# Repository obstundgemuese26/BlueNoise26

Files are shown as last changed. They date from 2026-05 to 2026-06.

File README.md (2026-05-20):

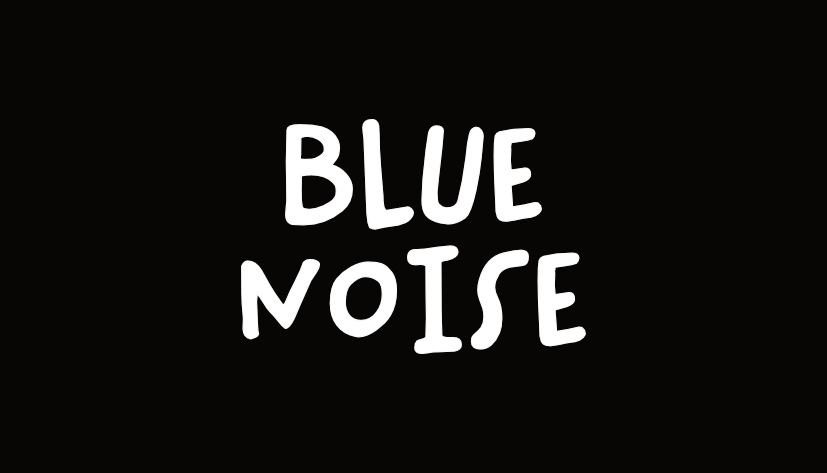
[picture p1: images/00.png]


### Open-source Wireless Jamming Pentesting Device using ESP32-WROOM-32U & 2 NRFL01+PA+LNA Modules

 ---
# WHAT DOES IT DO?

**IT CREATES NOISE SIGNAL TO JAM BLUETOOTH AND WIFI USING NRF24L01 AND ESP32 IN RANGE 2.4GHZ DEVICES, EFFECTS MAY VARY DEPENDS ON DEVICE BLUETOOTH VERSIONS....WARNING!!! JAMMING IS ILLEGAL**

---

## REQUIRED DEVICE AND MODULE:
1. `NRF24L01+ PLUS – PA LNA SMA Antenne`
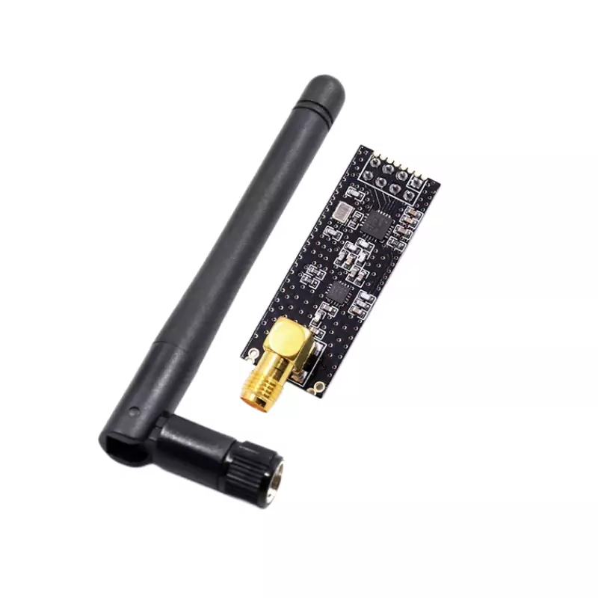
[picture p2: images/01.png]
-  

2. `1pc ESP32U` 
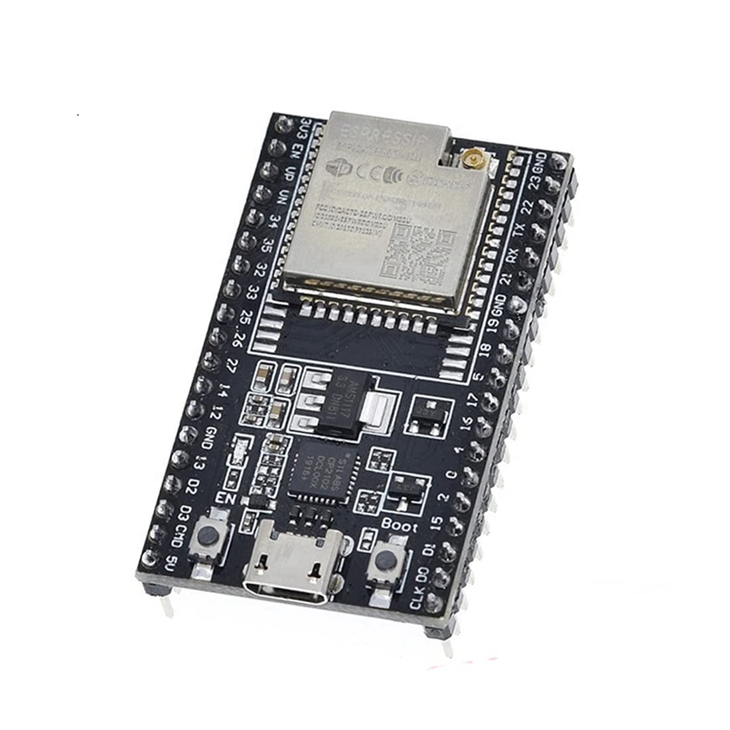
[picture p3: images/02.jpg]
- 

3. `25V 47UF CAPACITORF` 
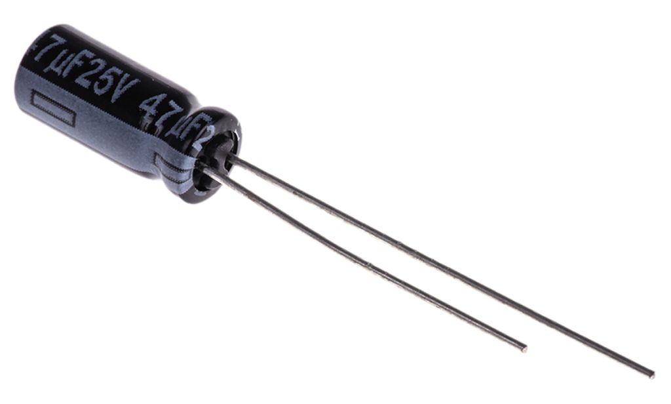
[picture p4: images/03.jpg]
- 

4. `1 DIP SWITCH` 
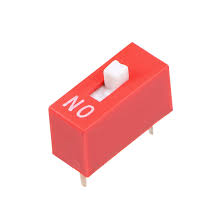
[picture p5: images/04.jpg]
- 

5. `DC Voltage Regulator Step Down Converter 4.5 V-12 V to 3.3 V/5 V 800 mA Power Supply Regulator Adjustment (5 Volt)` 
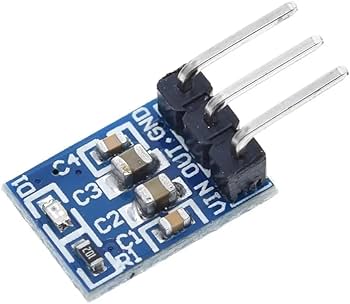
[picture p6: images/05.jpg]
- 

6. `9V Alkaline Batteries` 
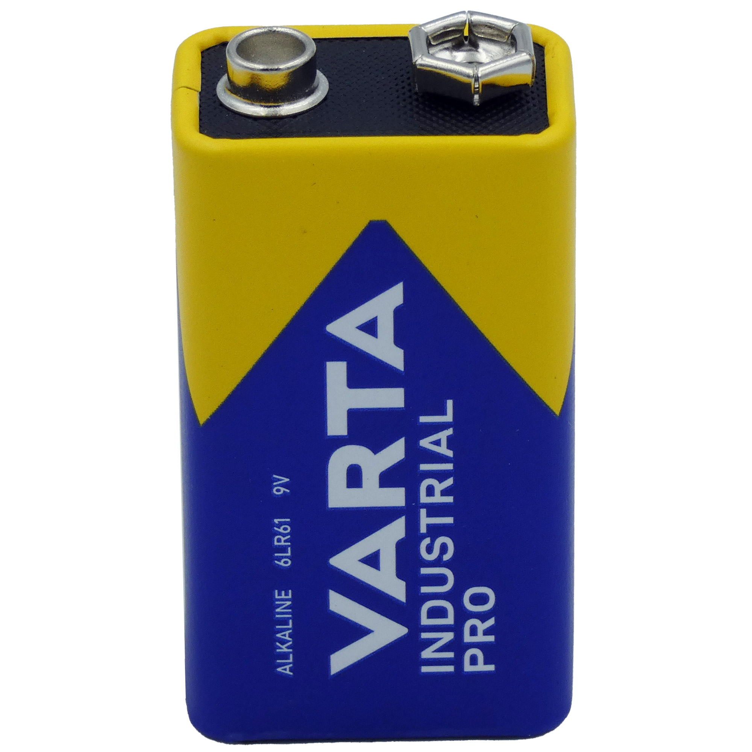
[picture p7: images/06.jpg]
- 

7. `9V Battery Holder` 
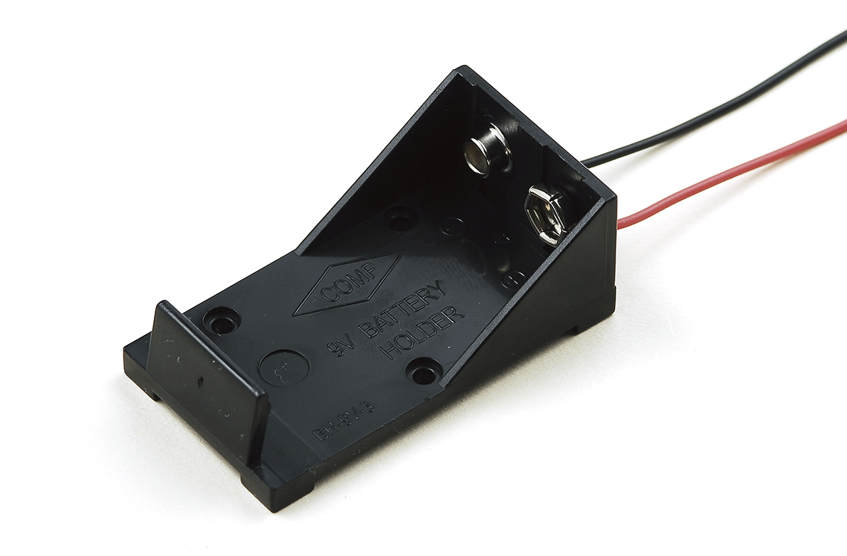
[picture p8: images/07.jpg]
- 

---
 ## CUSTOMIZED PCB BOARD IN EAGLE
 ### Brd File
 [Download PCB Files](pcb-board/BlueNoise-pcb-board.brd)

  ### Sch File
 [Download PCB Files](pcb-board/BlueNoise-pcb-board.sch)

---
 ## PINS TO ATTACH NRF24L01 TO ESP32

### FOR DUAL/TWO NRF24L01 
+ ` HSPI= SCK = 14, MISO = 12, MOSI = 13, CS = 15 , CE = 16`
+ ` VSPI= SCK = 18, MISO =19, MOSI = 23 ,CS =21 ,CE = 22`

### FOR SINGLE/ONE NRF24L01 YOU CAN CHOOSE BETWEEN HSPI OR VSPI 
 - `VSPI= SCK = 18, MISO =19, MOSI = 23 ,CS =21 ,CE = 22`
- `HSPI= SCK = 14, MISO = 12, MOSI = 13, CS = 15 , CE = 16` 

---

### Wiring
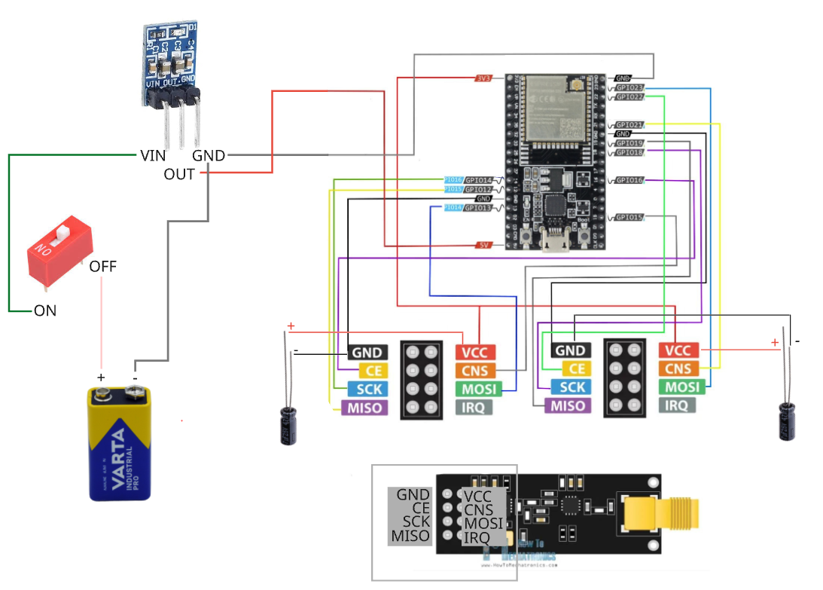
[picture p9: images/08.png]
wiring


---

## UPLOADING CODE TO ESP32
Connect ESP to your laptop
 
 1. `Download and install library "RF24 Master" in Arduino/ IDE`
 [Download RF24 Master](arduino/RF24-master(1).zip)

  2. `Download and install library "Button Master" in Arduino/ IDE`
 [Download Button Master](arduino/button-master(1).zip)

  3. Install ESP32 Board: Tools -> Board -> BoardManager <br>
  Search for: ESP -> select: "esp32 by Espressif Sytems" & click "Install"

  3. `Download the dual pin code and upload it in Arduino/ IDE`
 [Download Code](arduino/FORDUALPINS.ino)

## OR USE A WEBFLASHER: NO NEED TO DOWNLOAD INO FILE (USE CHROME OR MICROSOFT BROWSER) [WEBFLASHER](https://simonweckert.com/au5st3llung/COCO/flash/bluenoise/index.html) SELECT WHAT TO UPLOAD VSPI,HSPI OR DUAL AND CHOOSE RIGHT COM PORT
---

# SPECIAL THANKS
  * [ATOMNFT](https://github.com/dkyazzentwatwa/cypher-jammer?tab=readme-ov-file) - Cypher Jammer

  ---

# TROUBLESHOOTING

### python -m esptool --port COM3 --baud 115200 erase_flash

   ---

###  Phase 1: The Clean Slate (Complete Erase)

We will use a very slow speed (115200) to ensure stability.
Open CMD and type (don't hit enter yet):
python -m esptool --port COM3 --baud 115200 erase_flash
Hold the BOOT button on the ESP32.
Tap the EN/RST button once.
Hit Enter on your keyboard.
Release BOOT only after you see "Erasing..."

###  Phase 2: The Manual "Hard-Wire" (If Phase 1 fails)

If the buttons aren't triggering the bootloader, we bypass them with a jumper wire.
Connect a wire from GPIO 0 to GND.
Unplug and replug the USB.
Run the command:
python -m esptool --port COM3 --baud 115200 erase_flash

If it succeeds, remove the wire before trying to upload code again.

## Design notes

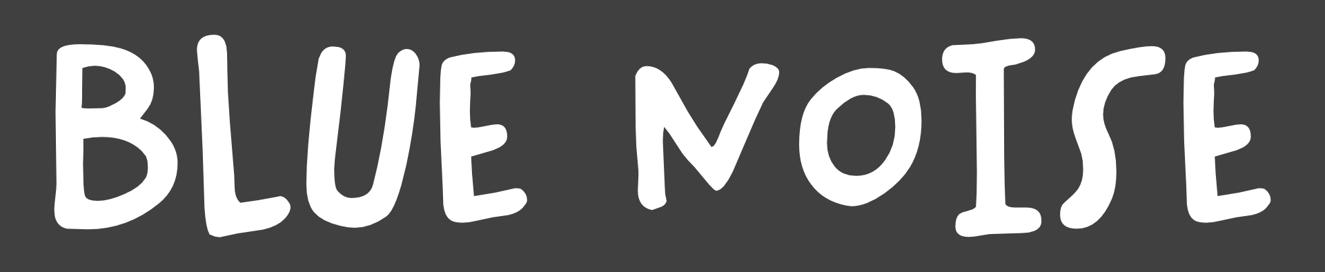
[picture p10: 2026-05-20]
images/title.png

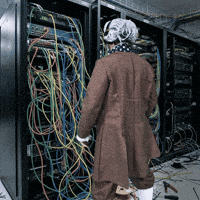
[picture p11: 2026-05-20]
images/GIF2.gif

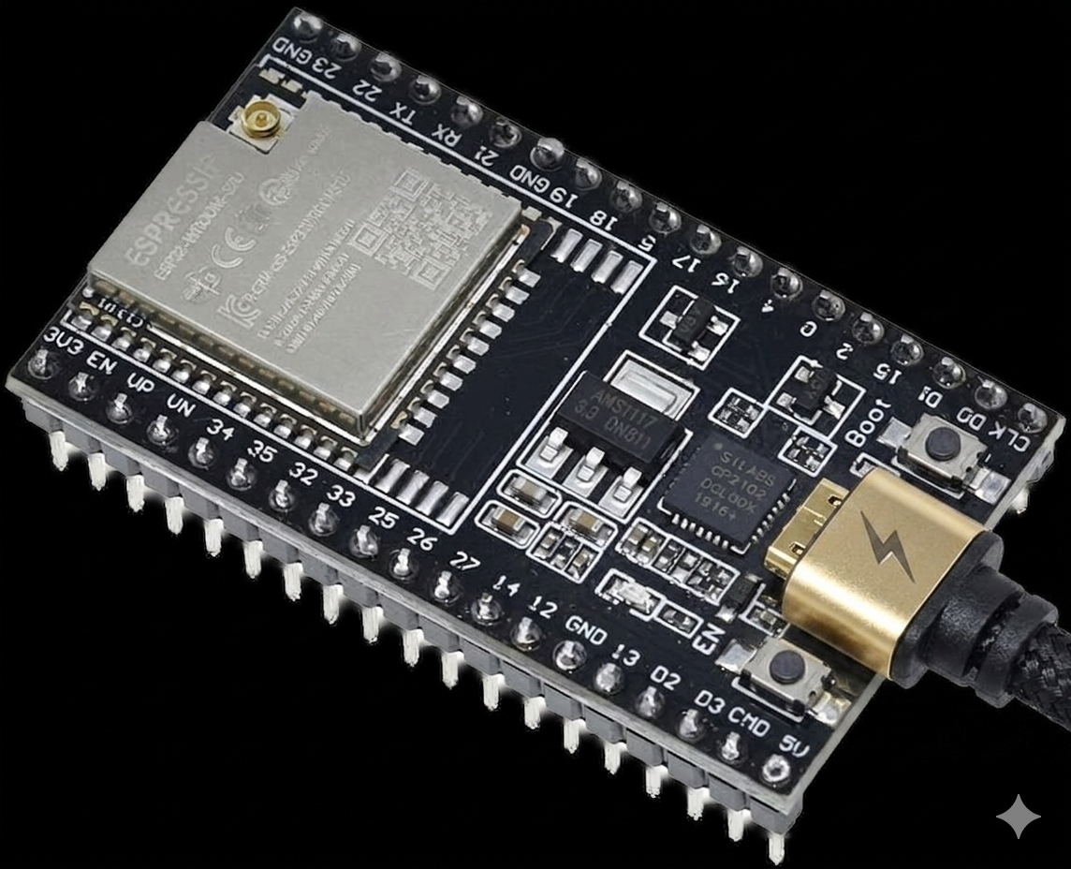
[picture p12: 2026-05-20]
images/plugin.png

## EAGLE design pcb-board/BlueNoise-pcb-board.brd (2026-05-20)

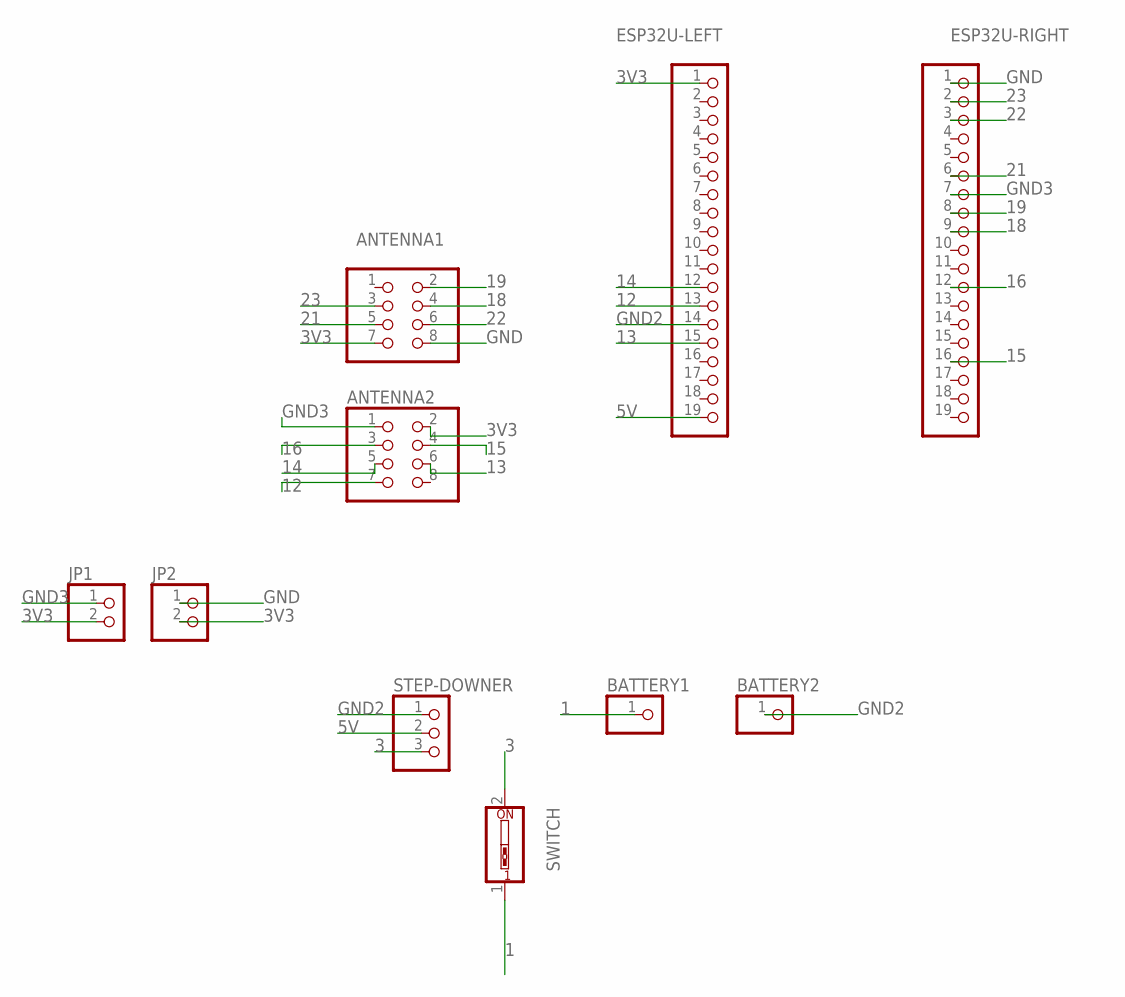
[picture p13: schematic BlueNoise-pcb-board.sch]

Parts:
ANTENNA1, ANTENNA2: PINHD-2X4; 2X04
BATTERY1, BATTERY2: PINHD-1X1; 1X01
ESP32U-LEFT, ESP32U-RIGHT: PINHD-1X19; 1X19
JP1, JP2: PINHD-1X2; 1X02
STEP-DOWNER: PINHD-1X3; 1X03
SWITCH: SW_DIP-1; EDG-01

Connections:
1: BATTERY1.1, SWITCH.1
3: STEP-DOWNER.3, SWITCH.2
3V3: ANTENNA1.7, ANTENNA2.2, ESP32U-LEFT.1, JP1.2, JP2.2
5V: ESP32U-LEFT.19, STEP-DOWNER.2
12: ANTENNA2.7, ESP32U-LEFT.13
13: ANTENNA2.6, ESP32U-LEFT.15
14: ANTENNA2.5, ESP32U-LEFT.12
15: ANTENNA2.4, ESP32U-RIGHT.16
16: ANTENNA2.3, ESP32U-RIGHT.12
18: ANTENNA1.4, ESP32U-RIGHT.9
19: ANTENNA1.2, ESP32U-RIGHT.8
21: ANTENNA1.5, ESP32U-RIGHT.6
22: ANTENNA1.6, ESP32U-RIGHT.3
23: ANTENNA1.3, ESP32U-RIGHT.2
GND: ANTENNA1.8, ESP32U-RIGHT.1, JP2.1
GND2: BATTERY2.1, ESP32U-LEFT.14, STEP-DOWNER.1
GND3: ANTENNA2.1, ESP32U-RIGHT.7, JP1.1

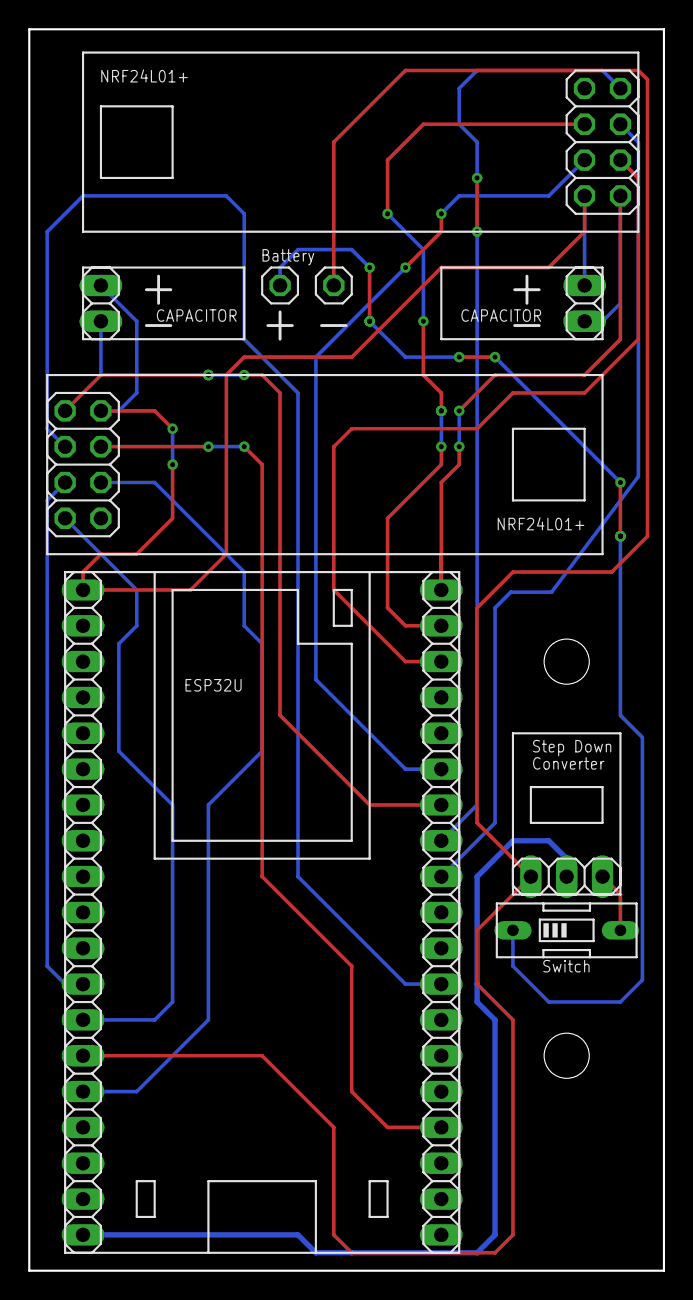
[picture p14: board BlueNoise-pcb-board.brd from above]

Board: 2 copper layers, 45.0 x 88.0 mm, 12 parts (0 on the bottom side), 17 nets.

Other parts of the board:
U$2, U$3: M3HOLE

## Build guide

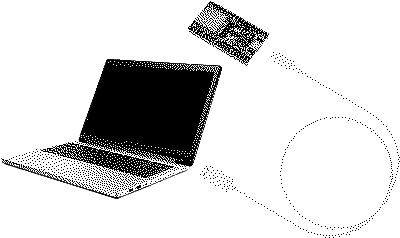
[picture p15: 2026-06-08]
images/HowtoUploadCode2.png

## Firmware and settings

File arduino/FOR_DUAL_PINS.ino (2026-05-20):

#include "RF24.h"
#include <SPI.h>
#include <ezButton.h>
#include "esp_bt.h"
#include "esp_wifi.h"


SPIClass *sp = nullptr;
SPIClass *hp = nullptr;

RF24 radio(16, 15, 16000000);   //HSPI CAN SET SPI SPEED TO 16000000 BY DEFAULT ITS 10000000
RF24 radio1(22, 21, 16000000);  //VSPI CAN SET SPI SPEED TO 16000000 BY DEFAULT ITS 10000000


//HSPI=SCK = 14, MISO = 12, MOSI = 13, CS = 15 , CE = 16
//VSPI=SCK = 18, MISO =19, MOSI = 23 ,CS =21 ,CE = 22

unsigned int flag = 0;   //HSPI// Flag variable to keep track of direction
unsigned int flagv = 0;  //VSPI// Flag variable to keep track of direction
int ch = 45;    // Variable to store value of ch
int ch1 = 45;   // Variable to store value of ch

ezButton toggleSwitch(33);




void two() {
  if (flagv == 0) {  // If flag is 0, increment ch by 4 and ch1 by 1

    ch1 += 4;
  } else {  // If flag is not 0, decrement ch by 4 and ch1 by 1

    ch1 -= 4;
  }

  if (flag == 0) {  // If flag is 0, increment ch by 4 and ch1 by 1
    ch += 2;

  } else {  // If flag is not 0, decrement ch by 4 and ch1 by 1
    ch -= 2;
  }

  // Check if ch1 is greater than 79 and flag is 0
  if ((ch1 > 79) && (flagv == 0)) {
    flagv = 1;                             // Set flag to 1 to change direction
  } else if ((ch1 < 2) && (flagv == 1)) {  // Check if ch1 is less than 2 and flag is 1
    flagv = 0;                             // Set flag to 0 to change direction
  }

  // Check if ch is greater than 79 and flag is 0
  if ((ch > 79) && (flag == 0)) {
    flag = 1;                            // Set flag to 1 to change direction
  } else if ((ch < 2) && (flag == 1)) {  // Check if ch is less than 2 and flag is 1
    flag = 0;                            // Set flag to 0 to change direction
  }
  radio.setChannel(ch);
  radio1.setChannel(ch1);
  /*Serial.print("SP:");
  Serial.println(ch1);
  Serial.print("\tHP:");
  Serial.println(ch);*/
}


void one() {
  ////RANDOM CHANNEL
  radio1.setChannel(random(80));
  radio.setChannel(random(80));
  delayMicroseconds(random(60));//////REMOVE IF SLOW


 /*  YOU CAN DO -----SWEEP CHANNEL
  for (int i = 0; i < 79; i++) {
    radio.setChannel(i);
*/

}



void setup() {

  /*Serial.begin(115200);*/
  esp_bt_controller_deinit();
  esp_wifi_stop();
  esp_wifi_deinit();
  esp_wifi_disconnect();
  toggleSwitch.setDebounceTime(50);

  initHP();
  initSP();
}

void initSP() {
  sp = new SPIClass(VSPI);
  sp->begin();
  if (radio1.begin(sp)) {
    Serial.println("SP Started !!!");
    radio1.setAutoAck(false);
    radio1.stopListening();
    radio1.setRetries(0, 0);
    radio1.setPALevel(RF24_PA_MAX, true);
    radio1.setDataRate(RF24_2MBPS);
    radio1.setCRCLength(RF24_CRC_DISABLED);
    radio1.printPrettyDetails();
    radio1.startConstCarrier(RF24_PA_MAX, ch1);
  } else {
    Serial.println("SP couldn't start !!!");
  }
}
void initHP() {
  hp = new SPIClass(HSPI);
  hp->begin();
  if (radio.begin(hp)) {
    Serial.println("HP Started !!!");
    radio.setAutoAck(false);
    radio.stopListening();
    radio.setRetries(0, 0);
    radio.setPALevel(RF24_PA_MAX, true);
    radio.setDataRate(RF24_2MBPS);
    radio.setCRCLength(RF24_CRC_DISABLED);
    radio.printPrettyDetails();
    radio.startConstCarrier(RF24_PA_MAX, ch);
  } else {
    Serial.println("HP couldn't start !!!");
  }
}

void loop() {


  toggleSwitch.loop();  // MUST call the loop() function first

  /* if (toggleSwitch.isPressed())
    Serial.println("one");
  if (toggleSwitch.isReleased())
    Serial.println("two");*/

  int state = toggleSwitch.getState();


  if (state == HIGH)
    two();

  else {
    one();
  }
}

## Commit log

2026-05-20 Create arduino
2026-05-20 Create pcb-board
